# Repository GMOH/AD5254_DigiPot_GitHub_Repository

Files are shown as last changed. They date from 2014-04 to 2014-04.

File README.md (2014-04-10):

AD5254_DigiPot_GitHub_Repository
================================

    AD525X Digital potentiometer code.
    
    More documentation can be found at http://familia-herrera.com/wordpress/archives/576
    Copyright (C) 2014  Guillermo Herrera

    This program is free software: you can redistribute it and/or modify
    it under the terms of the GNU General Public License as published by
    the Free Software Foundation, either version 3 of the License, or
    (at your option) any later version.

    This program is distributed in the hope that it will be useful,
    but WITHOUT ANY WARRANTY; without even the implied warranty of
    MERCHANTABILITY or FITNESS FOR A PARTICULAR PURPOSE.  See the
    GNU General Public License for more details.

    You should have received a copy of the GNU General Public License
    along with this program.  If not, see <http://www.gnu.org/licenses/>.
   
Notes:
Currently the files are standalone files, fully functional.  The Goal is to make a library that can be dropped in the arduino library folder with an example on how to use the code.  (Working on it)

Any help from others is welcome

ToDo:
1. Add open hardware license to EAGLE files
2. Create *.h and *.cpp and keywords.txt files for library
3. Update Website with more details and videos

Change Log:
4/8/14  First commit, arduino code files, EAGLE board files.
4/9/14  Added license file, description to individual files

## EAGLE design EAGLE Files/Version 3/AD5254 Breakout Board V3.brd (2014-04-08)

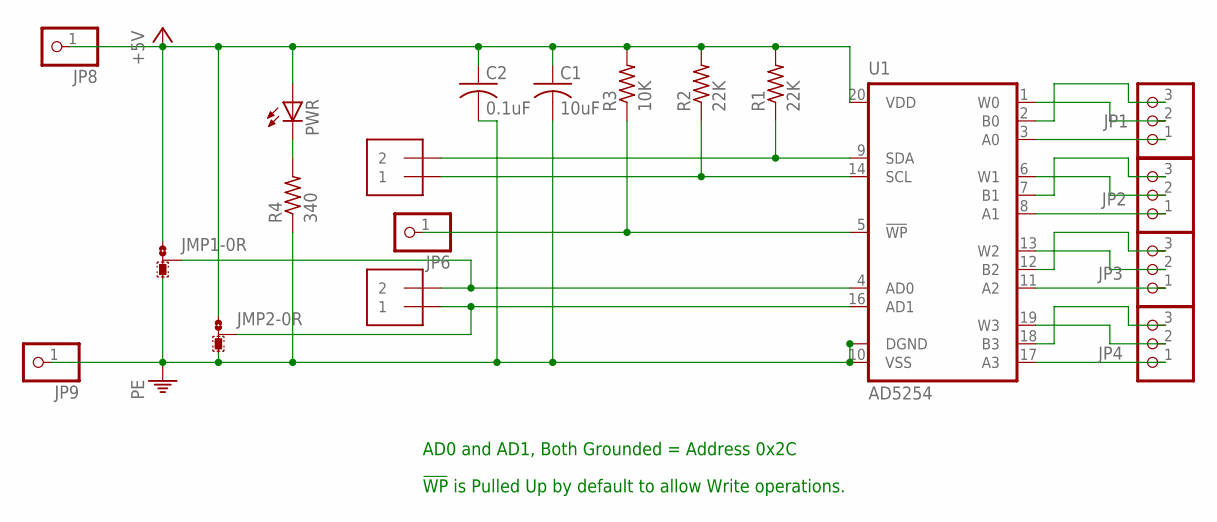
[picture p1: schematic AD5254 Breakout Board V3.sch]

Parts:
C1: 10uF; C0805
C2: 0.1uF; C0805
JMP1, JMP2: 0R-JUMPA; A0R-JMP
JP1, JP2, JP3, JP4: PINHD-1X3CB; 1X03-CLEANBIG
JP5, JP7: PINHD-1X2GD; 1X02-CLEANBIG
JP6, JP8, JP9: PINHD-1X1CB; 1X01-CLEANBIG
PWR: LED3MM
R1, R2: 22K; M0805
R3: 10K; M0805
R4: 340; M0805
U1: AD5254

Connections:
+5V: C1.1, C2.1, JMP1.1, JMP2.1, JP8.1, PWR.A, R1.2, R2.2, R3.2, U1.20 (VDD)
GND: C1.2, C2.2, JMP1.3, JMP2.3, JP9.1, R4.1, U1.10 (VSS), U1.15 (DGND)
unnamed: JP1.2, U1.1 (W0)
unnamed: JP6.1, R3.1, U1.5 (!WP)
unnamed: JP1.3, U1.2 (B0)
unnamed: JP1.1, U1.3 (A0)
unnamed: JP2.1, U1.8 (A1)
unnamed: JP3.1, U1.11 (A2)
unnamed: JP4.1, U1.17 (A3)
unnamed: JP4.3, U1.18 (B3)
unnamed: JP4.2, U1.19 (W3)
unnamed: JP2.3, U1.7 (B1)
unnamed: JP2.2, U1.6 (W1)
unnamed: JP3.3, U1.12 (B2)
unnamed: JP3.2, U1.13 (W2)
unnamed: JP5.2, R1.1, U1.9 (SDA)
unnamed: JP5.1, R2.1, U1.14 (SCL)
unnamed: JMP1.2, JP7.2, U1.4 (AD0)
unnamed: JMP2.2, JP7.1, U1.16 (AD1)
unnamed: PWR.K (C), R4.2

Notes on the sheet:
AD0 and AD1, Both Grounded = Address 0x2C
!WP! is Pulled Up by default to allow Write operations.

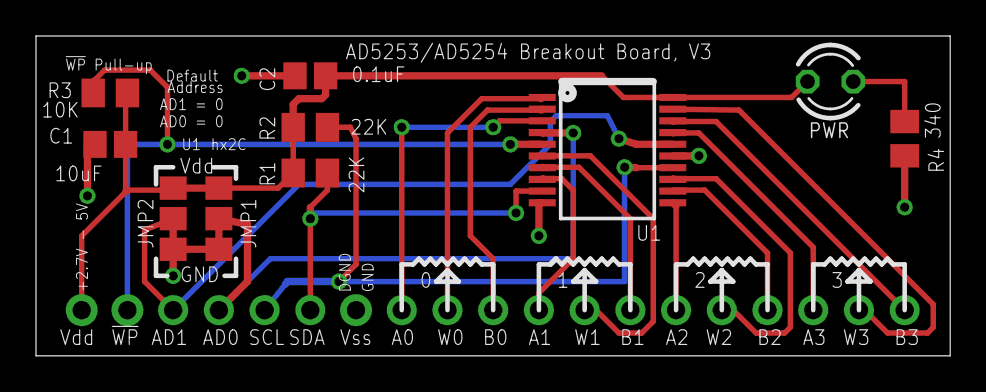
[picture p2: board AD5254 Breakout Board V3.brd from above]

Board: 2 copper layers, 50.8 x 17.8 mm, 19 parts (0 on the bottom side), 20 nets.

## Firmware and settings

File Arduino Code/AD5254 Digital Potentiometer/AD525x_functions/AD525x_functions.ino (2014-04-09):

/*  AD525X_functions.ino

    AD525X Digital potentiometer demo program.
    This code gives the user several options for the various read and write operations for the AD525X digi pots
    Values expected are from 0 to 255 for the write operations.
    
    More documentation can be found at http://familia-herrera.com/wordpress/archives/576
    Copyright (C) 2014  Guillermo Herrera

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
    You should have received a copy of the GNU General Public License
    along with this program.  If not, see <http://www.gnu.org/licenses/>.
    */
    
#include <Wire.h>

int RDAC0 = 0;
int RDAC1 = 1;
int RDAC2 = 2;
int RDAC3 = 3;

int EEMEM0= RDAC0 +32;
int EEMEM1= RDAC1 +32;
int EEMEM2= RDAC2 +32;
int EEMEM3= RDAC3 +32;

int RDACvalread;
int EEMEMvalread;
int valentered;
int address;
int num;

//Set up routine
void setup()
{
Serial.begin(9600);  // start serial for output
Serial.println("*********************************************************************");
Serial.println("AD525X Digital potentiometer  Copyright (C) 2014  Guillermo Herrera");
Serial.println("This program comes with ABSOLUTELY NO WARRANTY");
Serial.println("More info at http://familia-herrera.com/wordpress/archives/576");
Serial.println("*********************************************************************");
Serial.println("");
Wire.begin(); // join i2c bus (address optional for master)


//Reads all RDAC Current Values and prints them on serial
//readAllRDAC();
//byte rdac = readRDAC(0);
//Serial.print("RDAC0 Initial Value =");
//Serial.println(rdac,DEC);

//Reads all EEMEM Current Values and prints them on serial
//readAllEEMEM();
//byte eem = readEEMEM(1);
//Serial.println(eem,DEC);
}

//*********************Start Main Loop**********************
void loop()
{
Serial.println("Enter one of the folowing numbers");Serial.println(" ");
Serial.println(" 0. Read all EEMEMs and RDACs");Serial.println(" ");
Serial.print(" 1. Read RDAC0");Serial.print("\t");Serial.print("\t");
Serial.print(" 2. Read RDAC1");Serial.print("\t");Serial.print("\t");
Serial.print(" 3. Read RDAC2");Serial.print("\t");Serial.print("\t");
Serial.println(" 4. Read RDAC3");

Serial.print(" 5. Read EEMEM0");Serial.print("\t");Serial.print("\t");
Serial.print(" 6. Read EEMEM1");Serial.print("\t");Serial.print("\t");
Serial.print(" 7. Read EEMEM2");Serial.print("\t");Serial.print("\t");
Serial.println(" 8. Read EEMEM3");

Serial.print("11. Write RDAC0");Serial.print("\t");Serial.print("\t");
Serial.print("12. Write RDAC1");Serial.print("\t");Serial.print("\t");
Serial.print("13. Write RDAC2");Serial.print("\t");Serial.print("\t");
Serial.println("14. Write RDAC3");

Serial.print("15. Write EEMEM0");Serial.print("\t");
Serial.print("16. Write EEMEM1");Serial.print("\t");
Serial.print("17. Write EEMEM2");Serial.print("\t");
Serial.println("18. Write EEMEM3");
Serial.println(" ");

while (Serial.available() == 0);
{
 valentered = Serial.parseInt();
  switch (valentered)
 {
   //Write Cases
   case 1:
   address = RDAC0;
   num = 0;
   break;
   case 2:
   address = RDAC1;
   num = 1;
   break;
   case 3:
   address = RDAC2;
   num = 2;
   break;
   case 4:
   address = RDAC3;
   num = 3;
   break;
   case 5:
   address = EEMEM0;
   num = 0;
   break;
   case 6:
   address = EEMEM1;
   num = 1;
   break;
   case 7:
   address = EEMEM2;
   num = 2;
   break;
   case 8:
   address = EEMEM3;
   num = 3;
   break;
   
   //Read Cases
   case 11:
   address = RDAC0;
   num = 0;
   break;
   case 12:
   address = RDAC1;
   num = 1;
   break;
   case 13:
   address = RDAC2;
   num = 2;
   break;
   case 14:
   address = RDAC3;
   num = 3;
   break;
   case 15:
   address = EEMEM0;
   num = 0;
   break;
   case 16:
   address = EEMEM1;
   num = 1;
   break;
   case 17:
   address = EEMEM2;
   num = 2;
   break;
   case 18:
   address = EEMEM3;
   num = 3;
   break;
 }
//Read operations 
 if (valentered == 0)
 {
     readAllEEMEM();
     readAllRDAC();
 }
 else if (valentered >= 1 && valentered <= 4)
 {
   Serial.print("RDAC");
   Serial.print(num,DEC);
   Serial.print(" Value = ");
   RDACvalread = readRDAC (address);
   Serial.println(RDACvalread,DEC);
 }
 else if (valentered >= 5 && valentered <= 8)
 {
   Serial.print("EEMEM");
   Serial.print(num,DEC);
   Serial.print(" Value = ");
   EEMEMvalread = readEEMEM(address);
   Serial.println(EEMEMvalread,DEC);
 }
 
 //Write operations
  else if (valentered >= 11 && valentered <= 14)
 {
   Serial.print("Enter a value between 0 and 255 to send to RDAC");
   Serial.print(num,DEC);
   Serial.print(" and press enter ");
   while (Serial.available() == 0);
   {
     valentered = Serial.parseInt(); 
     RDACWrite(address, valentered);
   }
 }
 else if (valentered >= 15 && valentered <= 18)
 {
   Serial.print("Enter a value between 0 and 255 to send to RDAC");
   Serial.print(num,DEC);
   Serial.print(" and press enter ");
   while (Serial.available() == 0);
   {
     valentered = Serial.parseInt();
     EEMEMWrite(address, valentered);
   }
 }
 else
 {
   Serial.println("Not a valid selection");
 }
   
//   
// 
//
// 

}
Serial.println("");
}
//*************************End MAin Loop ***************************

//********************Start Function to Reads Current Value set for all EEMEM************
void readAllEEMEM()
{
Wire.beginTransmission(0x2c); // transmit to device U1 (0x2c or hex for 0101100)
Wire.write(0x20);
Wire.endTransmission();
Wire.requestFrom(0x2c, 4);
int eemnum = 0;
while(Wire.available())    // slave may write less than requested
{
byte eem = Wire.read(); // read a byte as character
Serial.print("EEMEM");
Serial.print(eemnum,DEC);
Serial.print(" = ");
Serial.print(eem,DEC);         // print the character
Serial.print(" ");
eemnum++;
}
Serial.println(" ");
}
//**************************END Function************************************************

// ************Start Function to Read All RDAC Current Values**********
int readAllRDAC()
{
Wire.beginTransmission(0x2c); // transmit to device U1 (0x2c or hex for 0101100)
Wire.write(0x00);
Wire.endTransmission();
Wire.requestFrom(0x2c, 4);  //Request four bytes from 
int rdacnum = 0;
while(Wire.available())    // slave may write less than requested
{
byte rdac = Wire.read(); // read a byte as character
Serial.print("RDAC");
Serial.print(rdacnum,DEC);
Serial.print(" = ");
Serial.print(rdac,DEC);         // print the character
Serial.print(" ");
rdacnum++;
}
Serial.println(" ");
}
//*****************End Function*************************************


//***************Start Function to read Individual RDAC Current Value *******************
byte readRDAC(int address)
{
Wire.beginTransmission(0x2c); // transmit to device U1 (0x2c or hex for 0101100)
Wire.write(address);           //RDAC Address 0 - 3
Wire.endTransmission();
Wire.requestFrom(0x2c, 1);
byte rdac;
if(Wire.available()) {   // slave may write less than requested
rdac = Wire.read(); // read a byte as character
}
return (rdac);
}
//*********************END function*****************************************************


//************START Function to READ Indvidual EEMEM Values*****************************
byte readEEMEM(int address)
{
//address = address + 32;
Wire.beginTransmission(0x2c); // transmit to device U1 (0x2c or hex for 0101100)
Wire.write(address);         //RDAC Address 0 - 3
Wire.endTransmission();
Wire.requestFrom(0x2c, 1);
byte eem;
while(Wire.available())    // slave may write less than requested
{
eem = Wire.read(); // read a byte as character
}
return (eem);
}
//**********************END Function ****************************************************

//************************START Function to Write to individual RDAC*********************
void RDACWrite(int address, int value) {
Wire.beginTransmission(0x2c);
Wire.write(address);            // writes instruction byte to RDAC1 (0x01 or hex for 0000001)
Wire.write(value);
Wire.endTransmission();
}
//*******************************ENF Function*********************************************

//************************START Function to Write to individual EEMEM*********************
void EEMEMWrite(int address, int value) {
Wire.beginTransmission(0x2c);
Wire.write(address);            // writes Current Wipper Setting for RDAC to EEMEM (0x20 or hex for 0010000 DEC 32 for EEMEM0)
Wire.write(value);
//Wire.write(address + 32);
Wire.endTransmission();
}
//*******************************ENF Function*********************************************

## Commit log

2014-04-08 Initial Files
    First files, more info at:
    http://familia-herrera.com/wordpress/archives/576
    [AD5254 Breakout Board V3.brd, AD5254 Breakout Board V3.sch]
2014-04-09 Added license and more description to code
    Added license and more description to the code files.
    Still need to create a library. Currently all files have all the
    functions.
